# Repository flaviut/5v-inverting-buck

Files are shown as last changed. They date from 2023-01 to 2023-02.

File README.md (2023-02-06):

# Inverting buck-boost controller

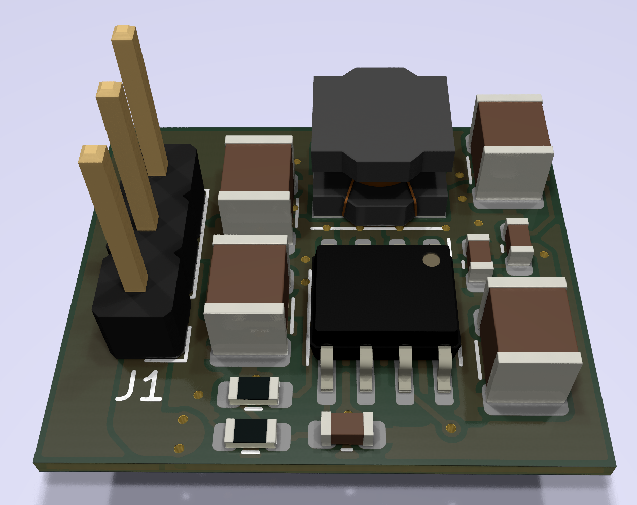
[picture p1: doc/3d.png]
3d view of project


Using the documentation in [TI's SLVA458B, "Creating an Inverting Power Supply Using a Synchronous Step-Down Regulator"][SLVA458B], I've designed an inverting buck-boost regulator using the super-cheap Aerosemi MT2499A, and characterized its performance somewhat.

[SLVA458B]: https://www.ti.com/lit/an/slva458b/slva458b.pdf?ts=1675589999464

schematic

[board layers](doc/layers.pdf)

## Testing

There's a massive amount of 7kHz ripple, up to 500mV before stopping testing at 300mA.

This seems to be related to very poor regulator stability. Placing 33pF in C5 improves ripple to 30mV between 0-220mA out, but the ripple is back to 500mV at 230mA.

|Cff |Imax |
|----|-----|
|32pF|225mA|
|54pF|285mA|

Linear interpolation indicates 133pF would be needed for stability at 500mA, but I'm not sure if linear interpolation is valid here.

I also suspect that it is not possible to create a perfectly compensated regulator here, since the MT2499A is internally compensated, and the procedure that SLVA458B describes to compensate the regulator is just not possible.

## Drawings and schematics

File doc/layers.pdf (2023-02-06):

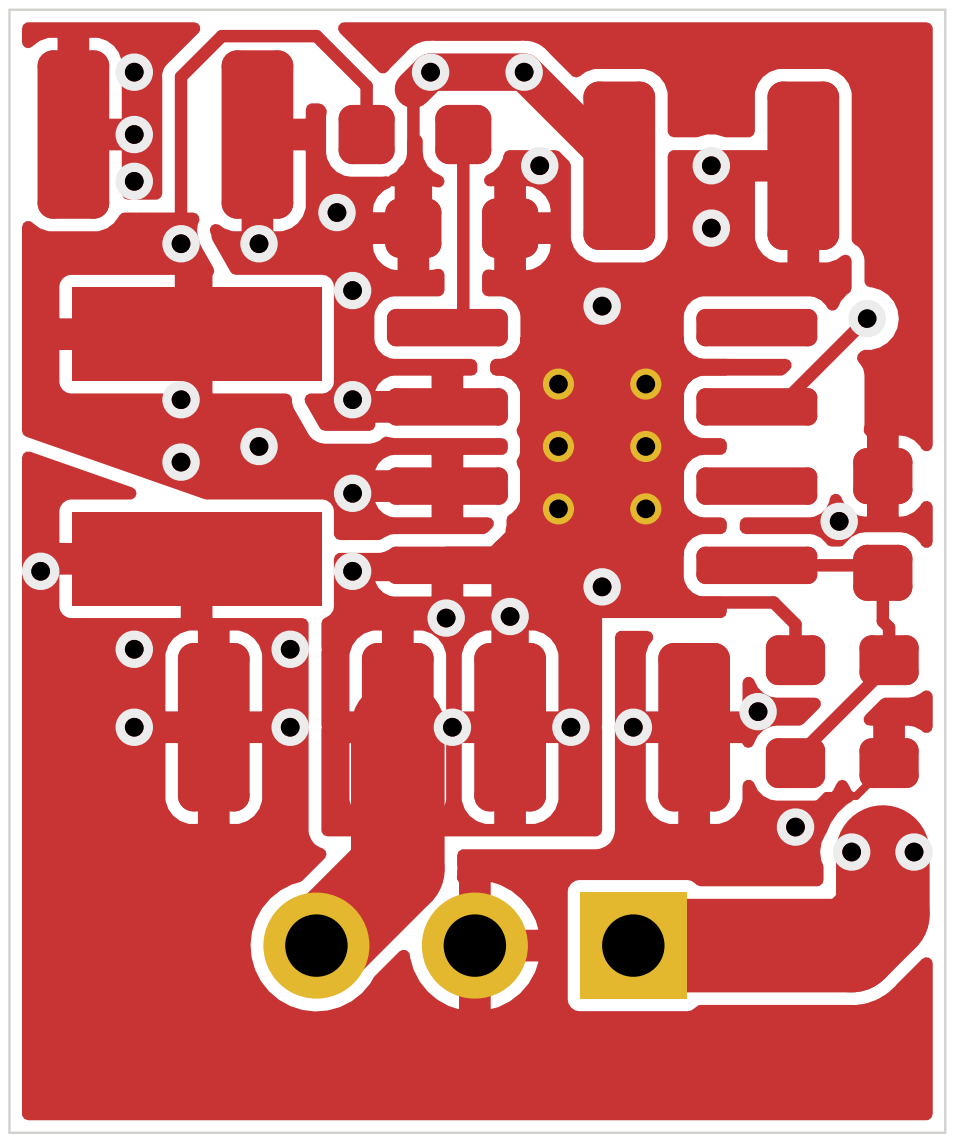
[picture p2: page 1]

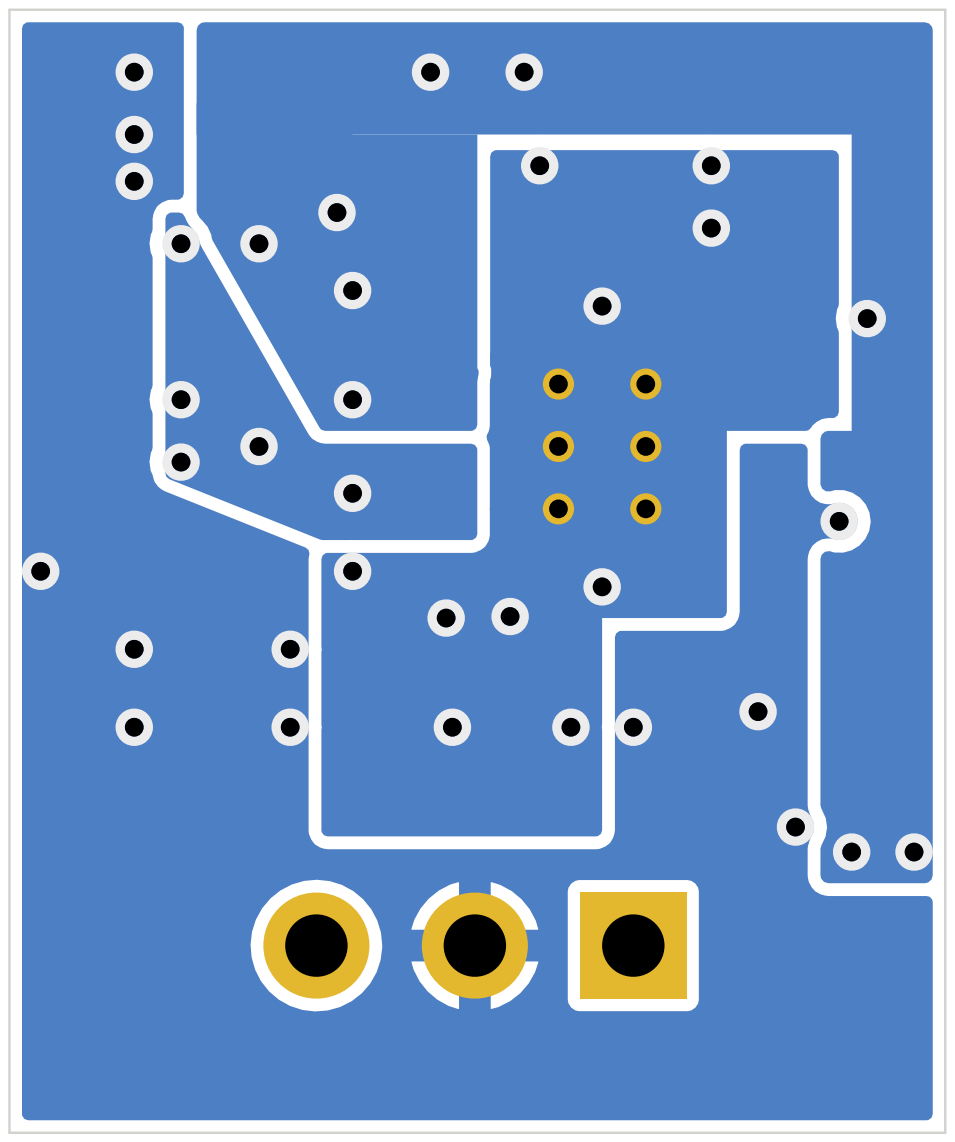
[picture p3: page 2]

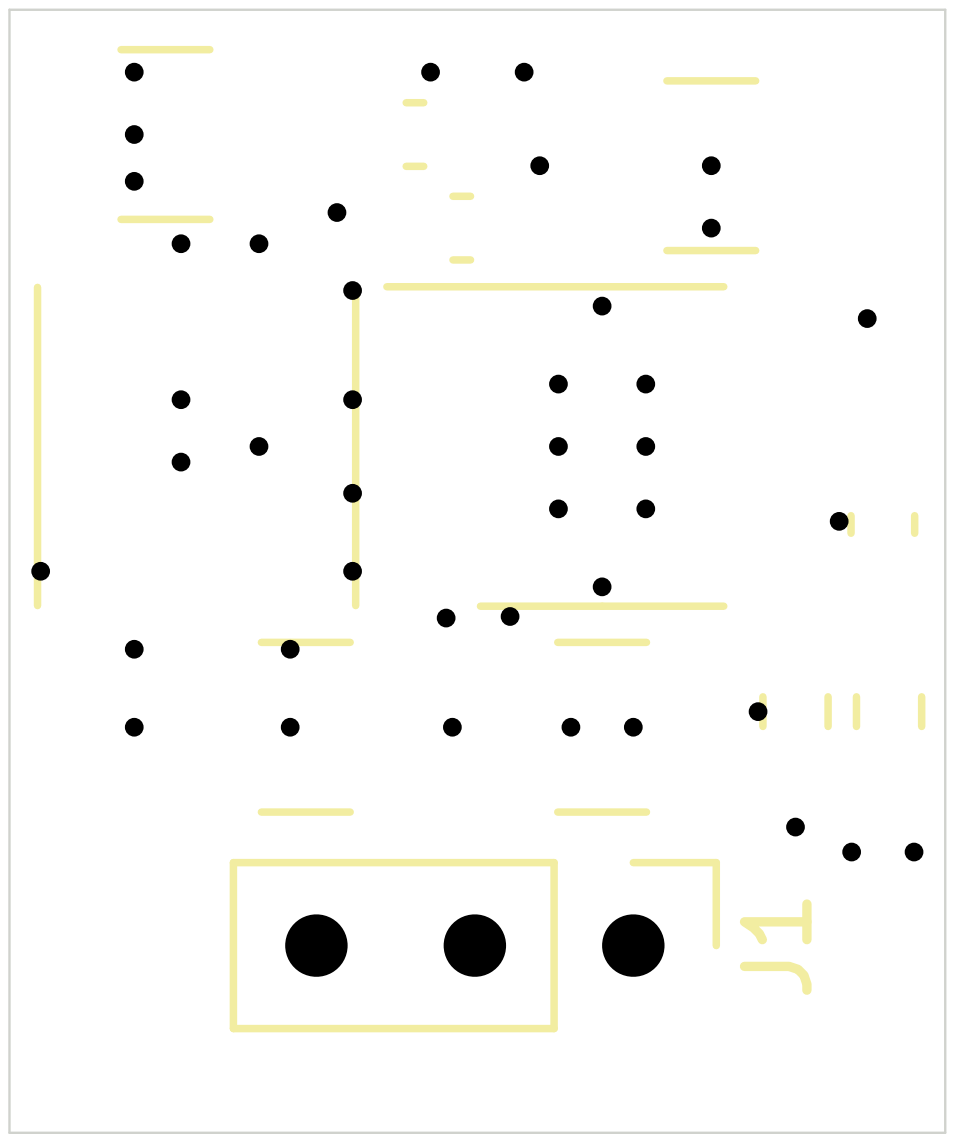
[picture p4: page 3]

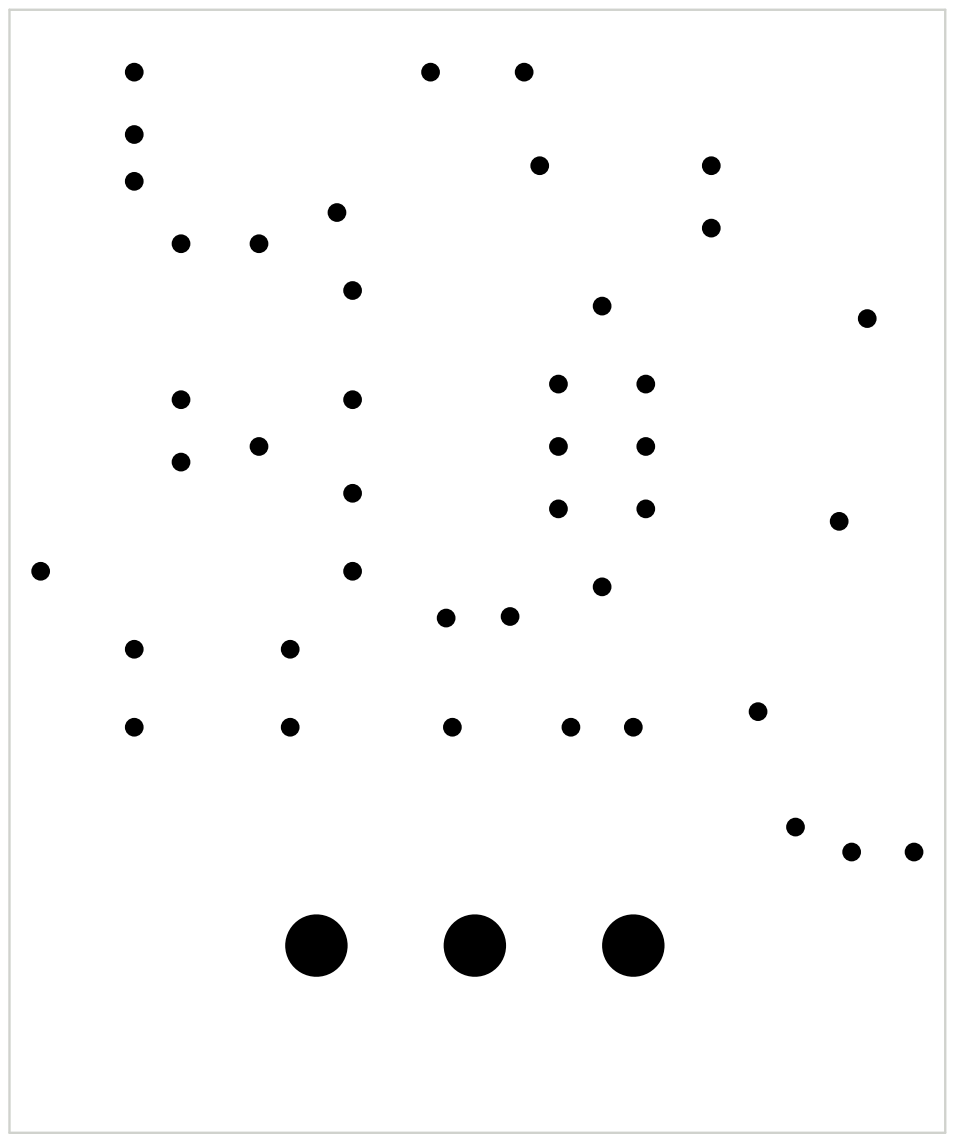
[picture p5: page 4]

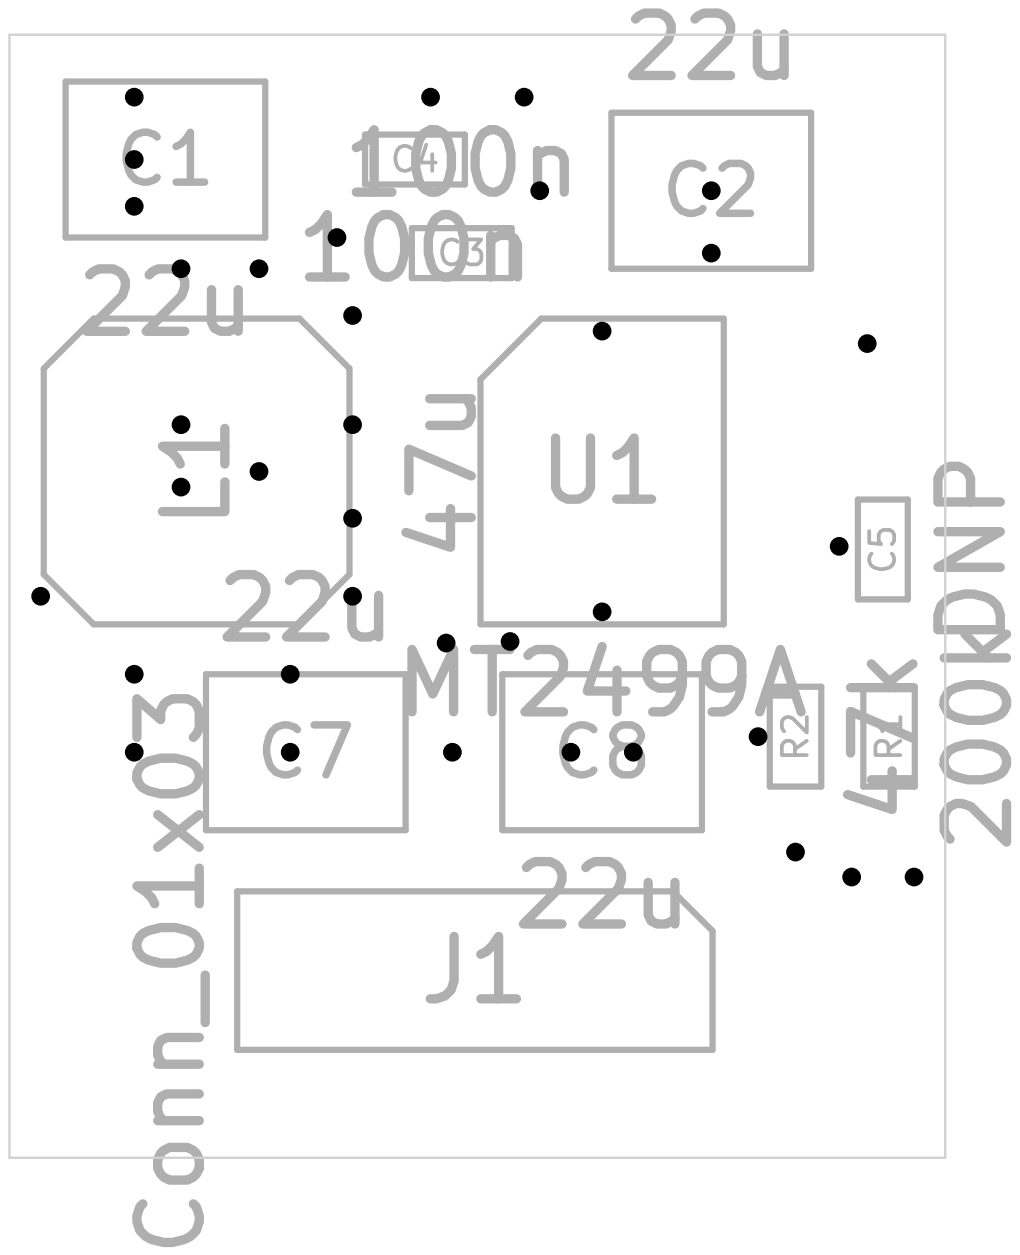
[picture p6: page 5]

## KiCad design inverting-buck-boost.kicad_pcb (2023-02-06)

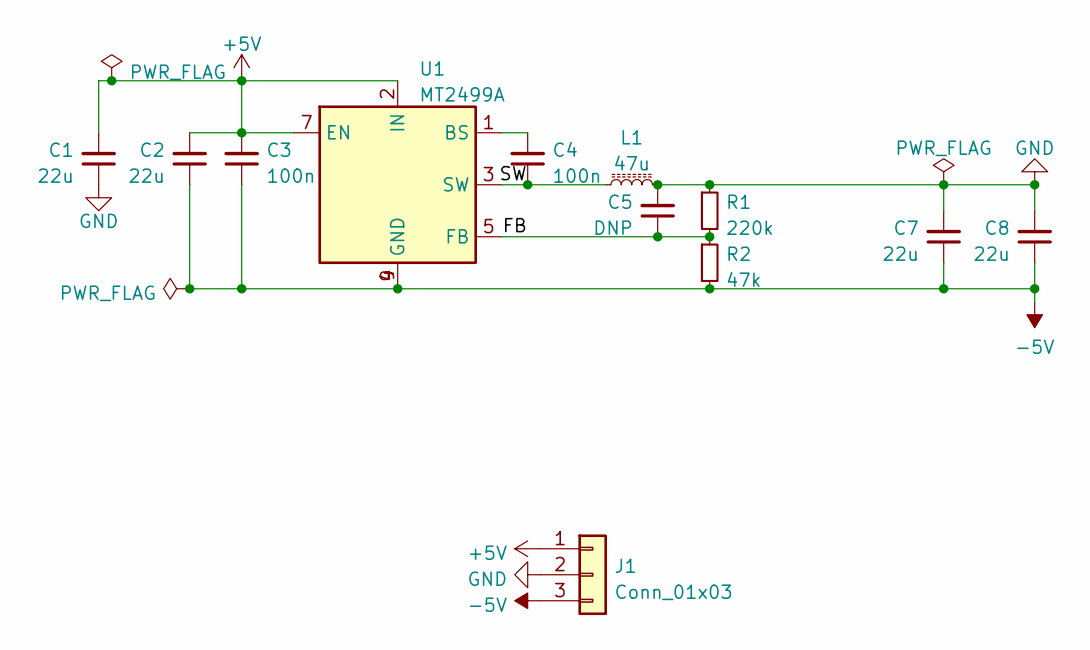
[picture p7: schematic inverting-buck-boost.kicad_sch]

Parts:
C1, C2, C7, C8: 22u; C_1210_3225Metric; LCSC C12891
C3, C4: 100n; C_0603_1608Metric; LCSC C14663
C5: DNP; C_0603_1608Metric
J1: Conn_01x03; PinHeader_1x03_P2.54mm_Vertical
L1: 47u; L_Taiyo-Yuden_NR-50xx; LCSC C341038
R1: 220k; R_0603_1608Metric; LCSC C22961
R2: 47k; R_0603_1608Metric; LCSC C25819
U1: MT2499A; SOIC-8-1EP_3.9x4.9mm_P1.27mm_EP2.62x3.51mm_ThermalVias; LCSC C3007555

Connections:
+5V: C1.2, C2.2, C3.2, J1.1, U1.2 (IN), U1.7 (EN)
-5V: C2.1, C3.1, C7.1, C8.1, J1.3, R2.2, U1.4 (GND), U1.9 (GND)
/FB: C5.1, R1.2, R2.1, U1.5 (FB)
/SW: C4.1, L1.2, U1.3 (SW)
GND: C1.1, C5.2, C7.2, C8.2, J1.2, L1.1, R1.1
unnamed: C4.2, U1.1 (BS)

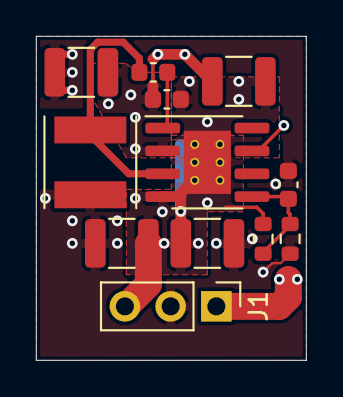
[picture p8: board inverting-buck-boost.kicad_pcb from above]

Board: 2 copper layers, 15.0 x 18.0 mm, 12 parts (0 on the bottom side), 6 nets.

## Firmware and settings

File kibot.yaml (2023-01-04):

# This is a working example.
# For a more complete reference use `--example`
kibot:
  version: 1

preflight:
  run_drc: true
  run_erc: true
  filters:
    - filter: connector silkscreen
      error: silk_over_copper
      regex: ".*on Edge.Cuts"
  update_xml: true


global:
  filters:
    # don't warn on excluded warnings
    - number: 58

filters:
- name: only_jlc_parts
  comment: Only parts with JLC (LCSC) code
  type: generic
  include_only:
  - column: LCSC
    regex: ^C\d+

variants:
- name: place_holder
  comment: Just a place holder for pre_transform filters
  type: kicost
  pre_transform:
  - _kicost_rename
  - _rot_footprint

outputs:
- name: basic_boardview
  comment: Board View export
  type: boardview
  dir: Assembly
- name: generic_bom_csv
  comment: Generic Bill of Materials in CSV format
  type: bom
  dir: Assembly
  options:
    format: CSV
    count_smd_tht: true
    group_fields: ['Part', 'Part Lib', 'Value', 'Footprint', 'Footprint Lib', 'Description']
- name: JLCPCB_gerbers
  comment: Gerbers compatible with JLCPCB
  type: gerber
  dir: Manufacturers/JLCPCB
  options:
    exclude_edge_layer: true
    exclude_pads_from_silkscreen: true
    plot_sheet_reference: false
    plot_footprint_refs: true
    plot_footprint_values: false
    force_plot_invisible_refs_vals: false
    tent_vias: true
    use_protel_extensions: true
    create_gerber_job_file: false
    disable_aperture_macros: true
    gerber_precision: 4.6
    use_gerber_x2_attributes: false
    use_gerber_net_attributes: false
    line_width: 0.1
    subtract_mask_from_silk: true
    inner_extension_pattern: .gp%n
  layers:
  - layer: F.Cu
    suffix: F_Cu
    description: Front copper
  - layer: B.Cu
    suffix: B_Cu
    description: Bottom copper
  - layer: B.Paste
    suffix: B_Paste
    description: Bottom solder paste
  - layer: F.Paste
    suffix: F_Paste
    description: Front solder paste
  - layer: B.Silkscreen
    suffix: B_Silkscreen
    description: Bottom silkscreen (artwork)
  - layer: F.Silkscreen
    suffix: F_Silkscreen
    description: Front silkscreen (artwork)
  - layer: B.Mask
    suffix: B_Mask
    description: Bottom soldermask (negative)
  - layer: F.Mask
    suffix: F_Mask
    description: Front soldermask (negative)
  - layer: Edge.Cuts
    suffix: Edge_Cuts
    description: Board shape
- name: JLCPCB_drill
  comment: Drill files compatible with JLCPCB
  type: excellon
  dir: Manufacturers/JLCPCB
  options:
    pth_and_npth_single_file: false
    pth_id: -PTH
    npth_id: -NPTH
    metric_units: true
    map: gerber
    route_mode_for_oval_holes: false
    output: '%f%i.%x'
- name: JLCPCB_position
  comment: Pick and place file, JLCPCB style
  type: position
  dir: Manufacturers/JLCPCB
  options:
    variant: place_holder
    output: '%f_cpl_jlc.%x'
    format: CSV
    units: millimeters
    separate_files_for_front_and_back: false
    only_smd: true
    columns:
    - id: Ref
      name: Designator
    - Val
    - Package
    - id: PosX
      name: Mid X
    - id: PosY
      name: Mid Y
    - id: Rot
      name: Rotation
    - id: Side
      name: Layer
- name: JLCPCB_bom
  comment: BoM for JLCPCB
  type: bom
  dir: Manufacturers/JLCPCB
  options:
    output: '%f_%i_jlc.%x'
    exclude_filter: only_jlc_parts
    ref_separator: ','
    columns:
    - field: Value
      name: Comment
    - field: References
      name: Designator
    - Footprint
    - field: LCSC
      name: 'LCSC Part #'
    csv:
      hide_pcb_info: true
      hide_stats_info: true
      quote_all: true
    group_fields: ['Part', 'Part Lib', 'Value', 'Footprint', 'Footprint Lib', 'Description']
- name: JLCPCB
  comment: ZIP file for JLCPCB
  type: compress
  dir: Manufacturers
  options:
    files:
    - from_output: JLCPCB_gerbers
      dest: /
    - from_output: JLCPCB_drill
      dest: /
    - from_output: JLCPCB_position
      dest: /
    - from_output: JLCPCB_bom
      dest: /
- name: basic_ibom
  comment: Interactive HTML BoM
  type: ibom
  dir: Assembly
  options:
    include_tracks: true
    extra_fields: Description,AVL1,AVL1 P/N,AVL2,AVL2 P/N
- name: basic_navigate_results
  comment: Web page to browse the results
  type: navigate_results
  dir: Browse
  options:
    link_from_root: index.html
- name: basic_pdf_sch_print
  comment: Schematic in PDF format
  type: pdf_sch_print
  dir: Assembly
- name: report_full
  comment: Full design report
  type: report
  dir: Manufacturers
- name: panel
  type: panelize
  comment: 5x5 Panel
  dir: Manufacturers
  options:
    configs:
      - layout: {rows: 4, cols: 5}
        tabs: {type: "full"}
        cuts:
          type: "vcuts"
          clearance: "0.13mm"

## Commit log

2023-02-06 Fix resistor to be as designed
    [inverting-buck-boost.kicad_sch]
2023-02-06 Update 3d models
    [inverting-buck-boost.kicad_pcb]
2023-02-06 Add readme
    [data.ods]
2023-02-06 Remove inductor fill
    reduces parasitic capacitance
    [inverting-buck-boost.kicad_pcb]
